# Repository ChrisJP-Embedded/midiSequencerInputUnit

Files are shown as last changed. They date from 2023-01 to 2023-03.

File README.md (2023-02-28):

# Monophonic 128-Step Sequencer

This is an ongoing project which implements a BLE enabled hardware sequencer - a tool for aiding musical composition for midi (Musical Instrument Digital Interface) controlled devices such as synthesizers and drum machines. The project is based around the ESP32S3-WROOM-1 module, a low-cost wireless enabled module featuring a dual-core ESP32S3 MCU, as well as on-module flash and PSRAM.

This project features both custom firmware (written in C) and custom hardware design (all part selection, schematic and PCB design) using KiCAD 6. 

The sequencer input unit features an RGB lit 6 x 8 switch matrix which makes up the sequencer input grid, as well as a small form factor IPS display and rotary encoders in order to provide a GUI interface. The sequencer input unit communicates wirelessly (via Bluetooth low-energy) to a base unit which provides a wireless interface to the MIDI physical layer.

**Note: First stage prototype**
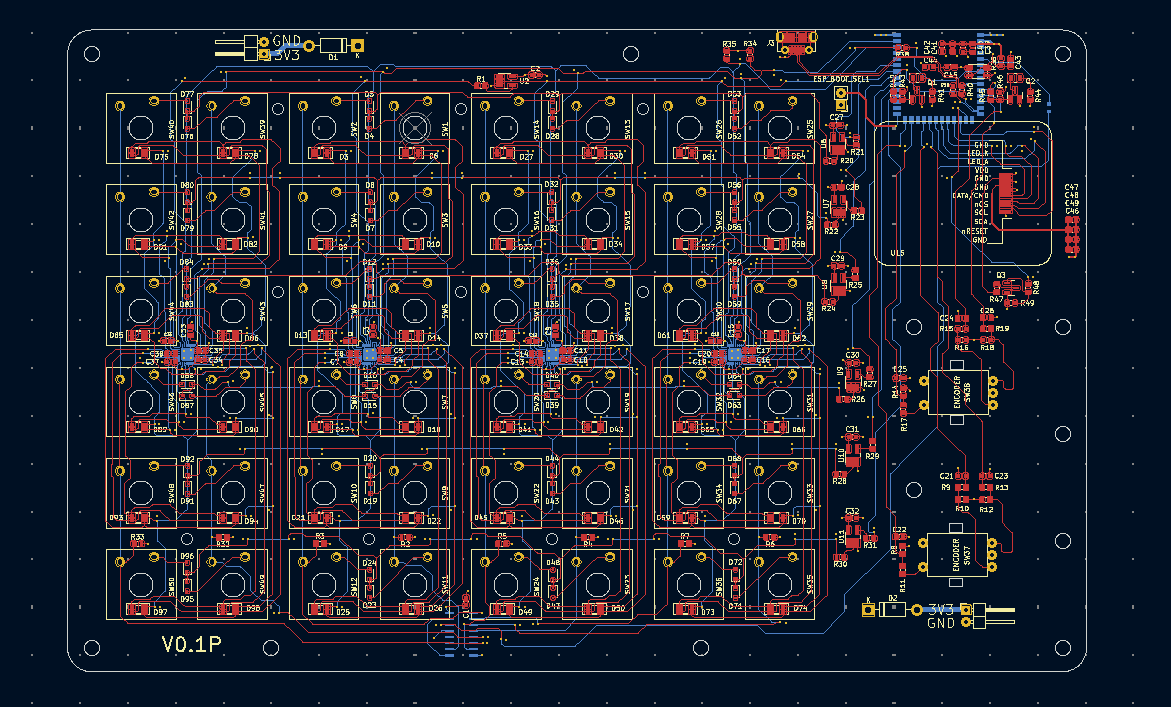
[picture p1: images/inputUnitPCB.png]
Model


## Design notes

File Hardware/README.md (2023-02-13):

# This is the Kicad 6 project for the 6 x 8 sequencer input unit.

**Summary**

NOTE: This is an initial prototype.

The sequencer grid is made up of a 6x8 switch matrix (using generic CherryMX style keyboard switches).

The inputs of each COLUMN of switches are connected to a common driving line. The outputs of ROW are connected to a common row scan/input line (each via signal diode).
The MCU clock a decade counter which drives the columns sequentially. Each row output passes through a schmitt trigger to the MCU for reading.

An I2C bus is used to control four TI LP5862 RGB LED drivers, which provide one RGB LED per switch.
The I2C bus trace widths are designed to keep the capacitance of the I2C bus within required spec.

Two rotary encoders (each with integrated SPST switch) provide additional UI functionality.
LPFs are present on encoder phase and switch outputs in order to provide some HW debouncing.

A small form factor IPS display is driven via SPI bus.

An ESP32S3 MCU controls the unit. USB port provides programming, console, and JTAG interface.
USB traces designed for 90ohm differential impedance.

Model

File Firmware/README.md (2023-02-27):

# Firmware architecture overview.
**NOTE: This project is ongoing**

The firmware is made up of a set of modules which are stored in the "components" directory.<br>

**Module descriptions**
(Intended as a brief overview, see the code for more details).

- **system**: The system module acts as the top level controller for the system as a whole.
- **gridManager**: [submodule of 'system'] Manages the grid data-structure, which holds all midi event data.
- **midiHelper**: Provides generic midi file processing helper functions.
- **guiMenu**: Provides a bespoke GUI menu system.
- **ipsDisplay**: Low-level driver for SPI controlled IPS display, which provides UI.
- **rotaryEncoders**: Low-level driver for two quadrature rotary encoders (each with SPST switch).
- **switchMatrix**: The switch matrix component detection of sequencer grid input events.
- **ledDrivers**: Low-level driver for four I2C controlled LP5862 RBG LED drivers, which provide additional UI for the sequencer input grid.
- **fileSys**: Handles all file system read/write operations. A port of littleFS provides the file system.
- **bleClient**: A Bluetooth low-energy GATT client which sends midi data to the GATT server during grid playback.

**The diagram below provides an overview of how the component modules are arranged into RTOS tasks and associated submodules**
    
```mermaid

    flowchart TD
        subgraph system_task["system [RTOS Task]"]
                subgraph fileSys
                    littleFS[littleFS]
                end
                subgraph gridManager
                    ledDrivers[ledDrivers]
                    midihelper[midiHelper]
                end
        end

        subgraph guiMenu_task["guiMenu [RTOS Task]"]
                ipsDisplay[ipsDisplay]
                rotaryEncoders[rotaryEncoders]
        end

        guiMenu_task--queue-->system_task
        system_task--queue-->guiMenu_task

         bleClient_task["bleClient [RTOS Task]"]

        bleClient_task--queue-->system_task
        system_task--queue-->bleClient_task
```

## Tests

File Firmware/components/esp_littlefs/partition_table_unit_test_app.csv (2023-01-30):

# Special partition table for unit test app
#
# Name | Type | SubType | Offset | Size | Flags
# Note: if you change the phy_init or app partition offset | make sure to change the offset in Kconfig.projbuild
nvs | data | nvs | 0x9000 | 0x4000
otadata | data | ota | 0xd000 | 0x2000
phy_init | data | phy | 0xf000 | 0x1000
factory | 0 | 0 | 0x10000 | 2M
# these OTA partitions are used for tests | but can't fit real OTA apps in them
# (done this way so tests can run in 2MB of flash.)
ota_0 | 0 | ota_0 |  | 64K
ota_1 | 0 | ota_1 |  | 64K
# flash_test partition used for SPI flash tests | WL FAT tests | and SPIFFS tests
fat_store | data | fat |  | 528K
spiffs_store | data | spiffs |  | 512K
flash_test | data | spiffs |  | 512K

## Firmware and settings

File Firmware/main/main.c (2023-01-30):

#define INCLUDE_vTaskSuspend 1
#define configSUPPORT_DYNAMIC_ALLOCATION 1

#include <stdio.h>
#include <driver/gpio.h>
#include "system.h"


#define LOG_TAG "main"
#define LED0_IO 16
#define LED1_IO 17
#define LED_IO_CONFIG_MASK ((1ULL << LED1_IO) | (1ULL << LED0_IO))
#define ESP_INTR_FLAG_LEVEL1 1

static void setSystemLED(uint8_t led, bool isOnOff);

void app_main(void)
{
    gpio_config_t systemAliveLED;

    systemAliveLED.intr_type = GPIO_INTR_DISABLE;
    systemAliveLED.mode = GPIO_MODE_OUTPUT;
    systemAliveLED.pin_bit_mask = LED_IO_CONFIG_MASK;
    systemAliveLED.pull_down_en = false;
    systemAliveLED.pull_up_en = false;
    assert(gpio_config(&systemAliveLED) == ESP_OK);

    //setSystemLED(LED0_IO, true);

    //Enable per-pin intrrupt functionality, all gpio interrupts
    //share the same priority level. The only interrupts used on
    //this core are gpio driven so default priority level is fine
    assert(gpio_install_isr_service(ESP_INTR_FLAG_LEVEL1) == ESP_OK);

    while (1)
    {
        system_EntryPoint();
        assert(0);
    }
}


static void setSystemLED(uint8_t led, bool isOnOff)
{
    if (led == LED0_IO || led == LED1_IO)
    {
        if (isOnOff)
            gpio_set_level(led, 1);
        else
            gpio_set_level(led, 0);
    }
}

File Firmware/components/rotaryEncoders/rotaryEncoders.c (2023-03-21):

#include "esp_log.h"
#include "esp_attr.h"
#include "include/rotaryEncoders.h"
#include <driver/gpio.h>
#include "driver/gptimer.h"

#define LOG_TAG                 "rotaryEncoderComponent"
#define ENCODER0_SW_IO          48      //input pin
#define ENCODER1_SW_IO          45      //input pin
#define ENCODER0_PHA0_IO        18      //input pin
#define ENCODER0_PHA1_IO        8       //input pin
#define ENCODER1_PHA0_IO        21      //input pin
#define ENCODER1_PHA1_IO        14      //input pin
#define ENCODER_COUNT_PER_REV   4       //Count per revolution
#define ENCODER_QUEUE_SIZE      10

//All possible encoder output states
#define ENCODING_00     0
#define ENCODING_01     1
#define ENCODING_10     2
#define ENCODING_11     3

//Bit masks used to configure pins simultanously
#define ENCODER_SW_IO_CONFIG_MASK   ((1ULL << ENCODER0_SW_IO) | (1ULL << ENCODER1_SW_IO))
#define ENCODER_PHA_IO_CONFIG_MASK  ((1ULL << ENCODER0_PHA0_IO) | (1ULL << ENCODER1_PHA0_IO) | (1ULL << ENCODER0_PHA1_IO) | (1ULL << ENCODER1_PHA1_IO))


//---- Private ----//
static void setupDebounceTimer(void);
static void setupEncoderPins(void);
static void encoderPositionChange_ISR(void * eventParam);
static void encoderSwitchEvent_ISR(void * eventParam);
static bool alarmISR(gptimer_handle_t timer, const gptimer_alarm_event_data_t *edata, void *param);

//Each encoder requires an instance
//of this type to track is state
typedef struct
{
    uint8_t ccwCount;
    uint8_t cwCount;
} sEncoderCount_t;


//The sequencer has two rotary encoders, each of which has a built in momentary switch.
//The rortary encoder code is completely interrupt driven, no need for a dedicated RTOS task.

//The system refers to the encoder nearest the display as 'Encoder0' and the one below it as 'Encoder1'
//Encoder1 can be considered as the 'primary' encoder, used to navigate the menu system.
//Encoder0 is used when additional nested functionality is required.

//Throughout the code base the following enumerations are used to describe encoder events:
//encoder0_sw   ->  Encoder 0 switch has been pressed
//encoder0_cw   ->  Encoder 0 has been turned in the clockwise direction
//encoder0_ccw  ->  Encoder 0 has been turned in the counter-clockwise direction
//encoder1_sw   ->  Encoder 1 switch has been pressed
//encoder1_cw   ->  Encoder 1 has been turned in the clockwise direction
//encoder1_ccw  ->  Encoder 1 has been turned in the counter-clockwise direction


//This queue is shared with the host system as an extern and acts
//to communicate all encoder events from the module to the host system
QueueHandle_t g_EncodersQueueHandle;

//A timer is used to provide debouncing
//of the switches on each of the encoders
static gptimer_handle_t g_debounceTimerHandle = NULL;
static volatile bool g_isWaitingForDebounceTimer = false;


//---- Public
void rotaryEncoders_init(void)
{
    //Create queue that module will use to 
    //communicate all encoder events to the host system
    g_EncodersQueueHandle = xQueueCreate(ENCODER_QUEUE_SIZE, sizeof(uint8_t));
    assert(g_EncodersQueueHandle != NULL);

    //Attempt configuration of encoder GPIO pins
    setupEncoderPins();

    //Provide debounce for encoder switches
    setupDebounceTimer();
}


//---- Public
void rotaryEncoders_deinit(void)
{
    esp_err_t err = ESP_OK;

    err |= gpio_isr_handler_remove(ENCODER0_SW_IO);
    err |= gpio_isr_handler_remove(ENCODER1_SW_IO);
    err |= gpio_isr_handler_remove(ENCODER0_PHA0_IO);
    err |= gpio_isr_handler_remove(ENCODER0_PHA1_IO);
    err |= gpio_isr_handler_remove(ENCODER1_PHA0_IO);
    err |= gpio_isr_handler_remove(ENCODER1_PHA1_IO);
    assert(err == ESP_OK);

    err |= gpio_reset_pin(ENCODER0_SW_IO);
    err |= gpio_reset_pin(ENCODER1_SW_IO);
    err |= gpio_reset_pin(ENCODER0_PHA0_IO);
    err |= gpio_reset_pin(ENCODER0_PHA1_IO);
    err |= gpio_reset_pin(ENCODER1_PHA0_IO);
    err |= gpio_reset_pin(ENCODER1_PHA1_IO);
    assert(err == ESP_OK);
}


//---- Private
static void setupEncoderPins(void)
{
    static const uint8_t encoder0_eventParam = encoder0_event;
    static const uint8_t encoder1_eventParam = encoder1_event;

    gpio_config_t UIRotaryEncoderSWPins_conf = {};
    gpio_config_t UIRotaryEncoderPHAPins_conf = {};

    esp_err_t err = ESP_OK;

    UIRotaryEncoderSWPins_conf.intr_type = GPIO_INTR_POSEDGE;
    UIRotaryEncoderSWPins_conf.mode = GPIO_MODE_INPUT;
    UIRotaryEncoderSWPins_conf.pin_bit_mask = ENCODER_SW_IO_CONFIG_MASK;
    UIRotaryEncoderSWPins_conf.pull_down_en = false;
    UIRotaryEncoderSWPins_conf.pull_up_en = false;
    err |= gpio_config(&UIRotaryEncoderSWPins_conf);
    assert(err == ESP_OK);

    UIRotaryEncoderPHAPins_conf.intr_type = GPIO_INTR_ANYEDGE;
    UIRotaryEncoderPHAPins_conf.mode = GPIO_MODE_INPUT;
    UIRotaryEncoderPHAPins_conf.pin_bit_mask = ENCODER_PHA_IO_CONFIG_MASK;
    UIRotaryEncoderPHAPins_conf.pull_down_en = false;
    UIRotaryEncoderPHAPins_conf.pull_up_en = false;
    err |= gpio_config(&UIRotaryEncoderPHAPins_conf);
    assert(err == ESP_OK);
    
    err |= gpio_isr_handler_add(ENCODER0_SW_IO, encoderSwitchEvent_ISR, (void*)(&encoder0_eventParam));
    err |= gpio_isr_handler_add(ENCODER1_SW_IO, encoderSwitchEvent_ISR, (void*)(&encoder1_eventParam));
    err |= gpio_isr_handler_add(ENCODER0_PHA0_IO, encoderPositionChange_ISR, (void*)(&encoder0_eventParam));
    err |= gpio_isr_handler_add(ENCODER0_PHA1_IO, encoderPositionChange_ISR, (void*)(&encoder0_eventParam));
    err |= gpio_isr_handler_add(ENCODER1_PHA0_IO, encoderPositionChange_ISR, (void*)(&encoder1_eventParam));
    err |= gpio_isr_handler_add(ENCODER1_PHA1_IO, encoderPositionChange_ISR, (void*)(&encoder1_eventParam));
    assert(err == ESP_OK);
}


//---- Private
static void setupDebounceTimer(void)
{
    esp_err_t err = ESP_OK;

    gptimer_config_t timer_config = {
        .clk_src = GPTIMER_CLK_SRC_APB,
        .direction = GPTIMER_COUNT_UP,
        .resolution_hz = 1000000, // 1MHz
    };

    gptimer_event_callbacks_t cbs = {
        .on_alarm = alarmISR,
    };

    err |= gptimer_new_timer(&timer_config, &g_debounceTimerHandle);
    err |= gptimer_register_event_callbacks(g_debounceTimerHandle, &cbs, NULL);
    err |= gptimer_enable(g_debounceTimerHandle);
    assert(err == ESP_OK);
}


//----------------------------------------------------
//---- MODULE INTERRUPT ROUTINES BELOW THIS POINT ----
//----------------------------------------------------
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

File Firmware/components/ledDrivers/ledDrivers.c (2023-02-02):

#include "esp_log.h"
#include "ledDriverPrivates.h"
#include "driver/i2c.h"

#define LOG_TAG                 "LP5862Driver"
#define NUM_LED_DRIVER_ICS      4
#define LED_DRIVER_LATCH_IO     7       
#define LED_DRIVER_0_ADDR       3
#define I2C_MASTER_SCL_IO       2 
#define I2C_MASTER_SDA_IO       1
#define I2C_MASTER_NUM          0
#define I2C_MASTER_FREQ_HZ      1000000
#define I2C_MASTER_TIMEOUT_MS   1000
#define GRID_DEMO_NUM_COLOURS   4

//---- Private ----//
static inline void toggleDriverLatchPins(void);
static inline uint8_t getDriverAddressForTargetColumn(uint8_t columnNum);
static uint8_t I2CLedDriverWrite(uint16_t regAddr, uint8_t *data, uint16_t numBytes, ledDriverICAddr_t deviceAddr, bool isBroadcast);
static esp_err_t configureI2CPeripheral(void);

static bool hasModuleBeenInitialized = false;

//The sequencer grid is made up of 96 switches, arranged into a 6x8 (row x column) matrix.

//Each switch in the grid has its own assosiated RGB LED.
//In order to control/drive all RGB LEDs independently, four Texas Instruments LP5862 RGB driver ICs are used.
//Each of the driver IC's control RGB LEDs for two consecutive columns in the sequencer grid.

//See following docs for more details on the LP5862.
//'LP5862 Datasheet'
//'LP5860 11 × 18 LED Matrix Driver Register Maps' (also applies to LP5862)

//The LP5862 RGB driver ICs are connected to the MCU via a single I2C bus. Hardware configuration of the ICs
//is such that each driver has its own unique I2C address, the unique I2C addresses are specified in the enum
//type 'ledDriverICAddr_t' in the following configuration:

//ledDrvIC0  ->  drives RGB LEDs for column0 (left most column) and column1
//ledDrvIC1  ->  drives RGB LEDs for column2 and column3
//ledDrvIC2  ->  drives RGB LEDs for column4 and column5
//ledDrvIC3  ->  drives RGB LEDs for column6 and column7 (right most column)

//---- IMPORTANT ----//
//Unfortunatelty the I2C peripheral of the ESP32S3 MCU is NOT DMA capable, despite the datasheet 
//claiming that it is (p36/37 datasheet). Therefore all IDF I2C operations are BLOCKING.


//---- Public 
uint8_t ledDrivers_init(void)
{
    //assert(hasModuleBeenInitialized == false);

    uint8_t data[5] = {0};
    gpio_config_t ledDriverLatchPin_conf = {};

    //Latch pin is used to manually trigger
    //latch of PWM register values to outputs
    ledDriverLatchPin_conf.intr_type = GPIO_INTR_DISABLE;
    ledDriverLatchPin_conf.mode = GPIO_MODE_OUTPUT;
    ledDriverLatchPin_conf.pin_bit_mask = (1ULL << LED_DRIVER_LATCH_IO);
    ledDriverLatchPin_conf.pull_down_en = false;
    ledDriverLatchPin_conf.pull_up_en = false;

    if(hasModuleBeenInitialized == false)
    {
        if(gpio_config(&ledDriverLatchPin_conf) != ESP_OK)
        {
            ESP_LOGE(LOG_TAG, "Error: Fault initializing gpio");
            return 1;
        }

        if(configureI2CPeripheral() != ESP_OK)
        {
            ESP_LOGE(LOG_TAG, "Error: Fault initializing I2C periperhal");
            return 1;
        }
    }


    //***********************************
    //Prepare configuration register data
    //***********************************
    //See following docs:
    //'LP5862 Datasheet'
    //'LP5860 11 × 18 LED Matrix Driver Register Maps'

    //Chip ENABLED
    data[0] = 0x01;

    //Dev_initial REG
    //PWM freq = 62.5k
    //Data refresh mode = Mode 2
    //Max scan lines = 10
    data[1] = 0b01010011;    

    //Dev_config1 REG
    //Current sink delay = ON
    //PWM phase shift = ON
    //PWM scale mode = Exponential
    //Line swith blanking = 1us
    data[2] = 0b00000111;

    //Dev_config2 REG
    //All OFF or DISABLED
    data[3] = 0x00;

    //Dev_config3 REG
    //Up deghost enable = ENABLED
    //Max current = 15mA
    //Up deghost = VLED - 2.5V
    //Down deghost = weak deghosting
    data[4] = 0b01010111;
 
    hasModuleBeenInitialized = true;

    //LP586x has auto register increment on writes so we
    //can write the four registers in one I2C transaction
    I2CLedDriverWrite(CHIP_ENABLE_REG_ADDR, data, 5, 0, true);

    return 0;
}



//---- Public
uint8_t ledDrivers_writeSingleLed(uint8_t columnNum, uint8_t rowNum, rgbLedColour_t rgbColourCode)
{
    assert(hasModuleBeenInitialized == true);
    assert((rowNum < SYSTEM_NUM_ROWS) && (columnNum < SYSTEM_NUM_COLUMNS));

    uint8_t lookupIdx;         
    static uint8_t data[NUM_8BIT_PWM_REGISTES_PER_LED] = {0};

    //PWM register addresses are store in the array 'ledDriverPwmAddrRGB'
    //the code below looks up the BASE address of the three PWM
    //registers for the target RGB LED.
    if((columnNum == 0) || (columnNum % 2 == 0))    
    {
        lookupIdx = rowNum * NUM_8BIT_PWM_REGISTES_PER_LED;
    } 
    else
    {
        lookupIdx = (SYSTEM_NUM_ROWS * NUM_8BIT_PWM_REGISTES_PER_LED);
        lookupIdx += (rowNum * NUM_8BIT_PWM_REGISTES_PER_LED);
    }

    //**********************
    //Prepare PWM write data
    //**********************

    //As the RGB PWM registers for any given LED are sequential in memory 
    //we can just address the base PWM register (GREEN) for the target LED
    //as the driver will automatically auto-increment register address
    //as bytes are written

    //The RGB colour codes are 3-bytes, which specify the PWM 
    //values that must be written to generate the specified colour.
    //The most signficant byte of the colour code is the RED PWM value
    //The middle byte of the colour code is the GREEN PWM value
    //The least significant byte of the colour code is the BLUE PWM value

    //Now we need to load the colour code into the data buffer
    //in the required order (to match the order of PWM registers in memory)

    //Green PWM register
    data[0] = (uint8_t)((rgbColourCode & 0x00ff00) >> 8);
    //Red PWM register
    data[1] = (uint8_t)((rgbColourCode & 0xff0000) >> 16);
    //Blue PWM register
    data[2] = (uint8_t)((rgbColourCode & 0x0000ff));

    //ESP_LOGI(LOG_TAG, "idx: %d\n", lookupIdx);
    //ESP_LOGI(LOG_TAG, "PWM BASE: %0x\n", ledDriverPwmAddrRGB[lookupIdx]);

    I2CLedDriverWrite(ledDriverPwmAddrRGB[lookupIdx], data, NUM_8BIT_PWM_REGISTES_PER_LED, getDriverAddressForTargetColumn(columnNum), false);
    toggleDriverLatchPins();  //Need to toggle latch pin before PWM data latched to outputs

    return 0;
}
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

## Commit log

2023-02-23 fixed some module naming problems after refactoring
    [menu.c]
2023-02-27 removed unused dir and updated InputUnit firmware readme
    [partitions_demo_esp_littlefs.csv]
2023-02-28 Restructured repo directories, added readme.md to repo base
    [.bumpversion.cfg, Controller_Switch_Matrix_Module.kicad_sch, Encoders.kicad_sch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]
2023-03-22 Minor update to switch matrix loop
2023-03-22 Updated switchMatrix component
